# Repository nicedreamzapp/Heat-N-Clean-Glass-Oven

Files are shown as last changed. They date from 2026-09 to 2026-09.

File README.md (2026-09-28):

# Nice Dreamz Heat & Clean Glass Oven

**The perfect heat, every time. Drop in your terp slurper, banger, or ball vape -- the oven heats the entire barrel evenly to your exact target temperature. When you're done, crank it up and burn off all the char and resin too.**

**In one sentence:** an open-hardware design for a bolt-together stainless and ceramic oven that heats glass dab pieces to a set temperature with a PID controller, then runs hotter to burn them clean.

**Status:** design complete, 14-part metal fab package generated from Python CAD scripts, sheet thickness verified by measuring the STEP files. First physical articles are not in this repo yet (see [Known limits](#known-limits)).

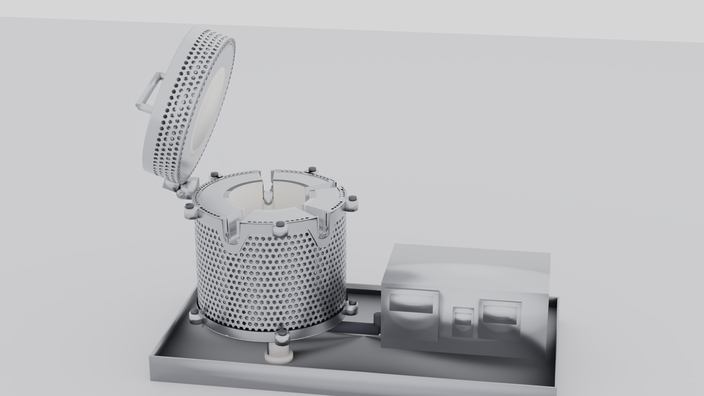
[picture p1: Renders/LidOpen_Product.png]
Nice Dreamz Heat & Clean Glass Oven - Lid Open


Heat & Clean is a precision ceramic oven that heats your glass pieces to the perfect dabbing or vaping temperature -- no torch, no guessing, no hot spots. Set your temp, drop in your piece, and get a perfect session every time. And when your glass gets gunked up? Same oven, higher temp, walk away. Comes back looking brand new.

**Spin every part in your browser — no CAD software needed:** https://nicedreamzapp.github.io/Heat-N-Clean-Glass-Oven/viewer-thickness.html
Click **Explode** to pull the oven apart, and every part is labelled with its sheet thickness.

**See every part in 3D (older viewer):** https://nicedreamzwholesale.com/heat-n-clean-viewer/all-parts.html
**Full parts list:** [PARTS_LIST.md](PARTS_LIST.md) · **Current fab package:** `CAD Exports/FAB_PACKAGE_2026-09-09/` — 14 STEP files + BOM

---

## What I built (Matt Macosko)

- **Parametric CAD generator**, all geometry in code: [Scripts/export_all_parts.py](Scripts/export_all_parts.py) (every part as STL/GLB), shared dimensions in [Scripts/hnc_params.py](Scripts/hnc_params.py), part builders [build_base_body.py](Scripts/build_base_body.py), [build_lid.py](Scripts/build_lid.py), [build_cap_shell_ring.py](Scripts/build_cap_shell_ring.py), [build_caps_tray.py](Scripts/build_caps_tray.py)
- **Fab package builder** for the 0.8 mm inner parts: [Scripts/build_inner_parts_08.py](Scripts/build_inner_parts_08.py) -> [CAD Exports/FAB_PACKAGE_2026-09-09/](CAD%20Exports/FAB_PACKAGE_2026-09-09/) (14 STEP files + [BOM](CAD%20Exports/FAB_PACKAGE_2026-09-09/BOM_metal_parts.csv))
- **Thickness verification** by ray-casting the STEP meshes: [Scripts/measure_thickness.py](Scripts/measure_thickness.py) -> [viewer-thickness/parts.json](viewer-thickness/parts.json), plus [Scripts/verify_steps.py](Scripts/verify_steps.py)
- **Flat patterns and shop drawings**: [generate_flat_patterns.py](Scripts/generate_flat_patterns.py), [generate_cap_dxfs.py](Scripts/generate_cap_dxfs.py), [generate_fab_package.py](Scripts/generate_fab_package.py) (bilingual EN/中文 spec)
- **Browser 3D viewers**: [viewer-thickness.html](viewer-thickness.html) and the other `viewer-*.html` pages
- **Controller configuration** for the upstream REX-C100 PID and DH48S timer: [Controller_Setup_Guide.md](Controller_Setup_Guide.md)
- **Parts list and assembly design** (25 pieces, zero welded joints): [PARTS_LIST.md](PARTS_LIST.md)

Upstream tools used, not written here: [build123d](https://github.com/gumyr/build123d) (STEP I/O), [trimesh](https://github.com/mikedh/trimesh), NumPy, [three.js](https://threejs.org/) (viewers), Blender (product renders). The REX-C100, DH48S and ceramic heater are off-the-shelf parts.

---

## Current metal spec (2026-09-09)

| | Parts | Sheet | Material |
|---|---|---|---|
| **Outside** — seen, structural | 02 outer tube · 04 bottom cap · 05 top cap · 07 lid outer tube · 08 lid top disk · 11 hinge strap | **1.2 mm** | 304SS, #4 brushed |
| **Inside** — hidden, no load | 01 inner wall · 03 support ring · 06 lid inner tube · 09 lid ceramic holder · 12 hold-down ring | **0.8 mm** | 304 **or** 430 SS / aluminized steel — anything rated 870 °F continuous |
| Tray | 14 steel tray | 3 mm | 304 or mild steel |
| Rod | 10 handle (Ø8) · 13 hinge pin (Ø5) | — | 304SS rod |

Inner wall ID stays 141.7 and the outer tube stays 152.1 / 154.5, so nothing that mates
with the ceramic or the glass moved. Every thickness above was measured back out of the
STEP files themselves (`Scripts/measure_thickness.py`), not copied from a spec sheet.

---

## The Problem

Torches and coil heaters can't evenly heat modern glass pieces.

| | |
|---|---|
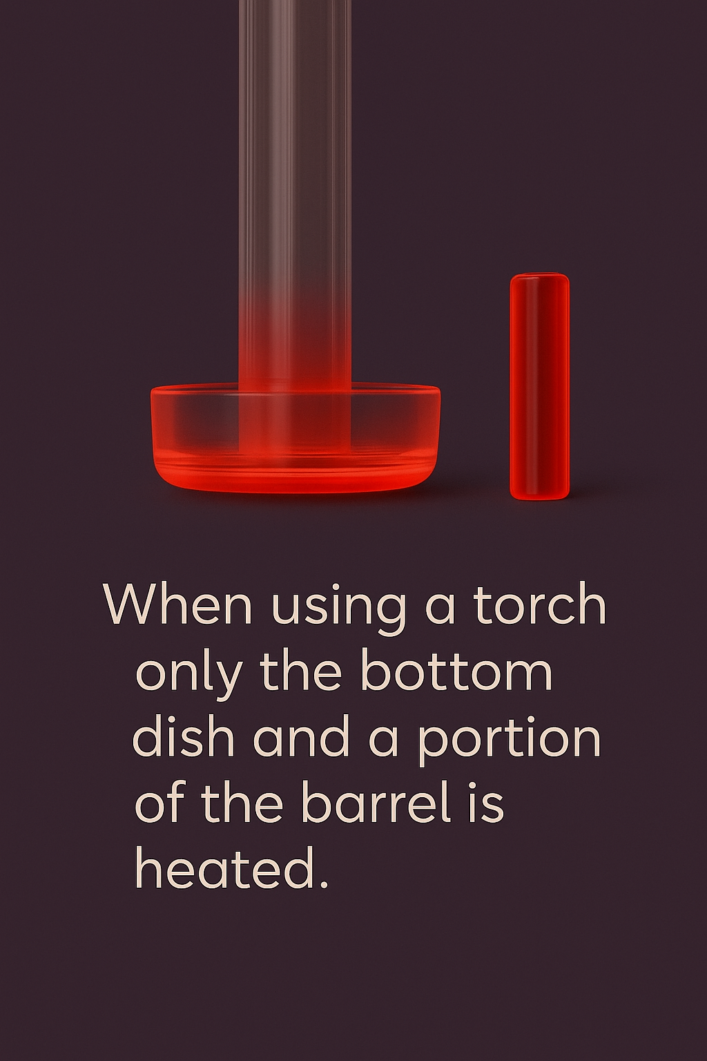
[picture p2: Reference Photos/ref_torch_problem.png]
Torch only heats the bottom
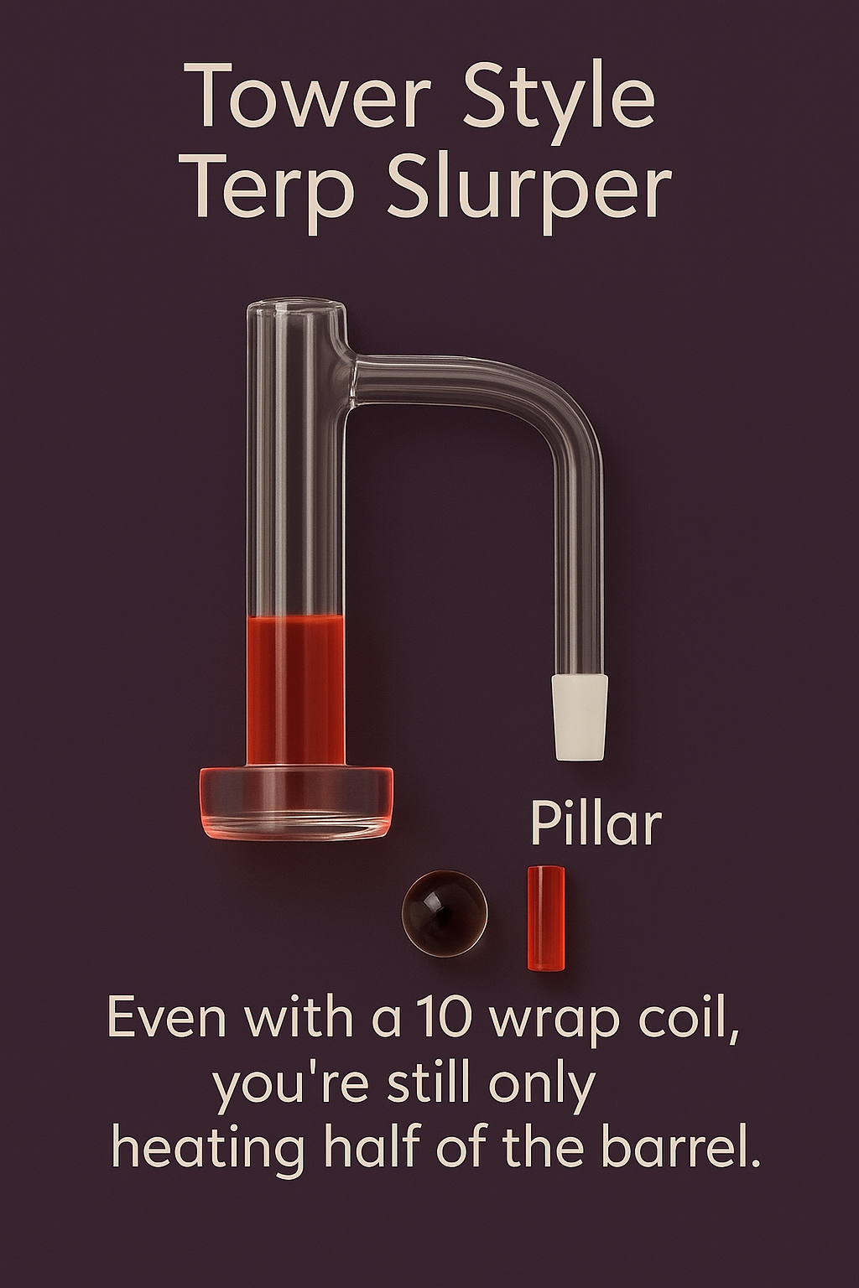
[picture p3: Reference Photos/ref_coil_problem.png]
Coil wraps only cover half the barrel
|  |  |

**With a torch**, only the bottom dish and a small portion of the barrel gets heated. You're guessing at temperature every single time -- too hot and you scorch it, too cool and you waste product.

**With a coil heater**, even a 10-wrap coil only covers half the barrel. The top half never reaches temp. Uneven heat means uneven flavor.

---

## The Solution

The Heat & Clean oven surrounds the **entire piece** in even, controlled heat.

| | |
|---|---|
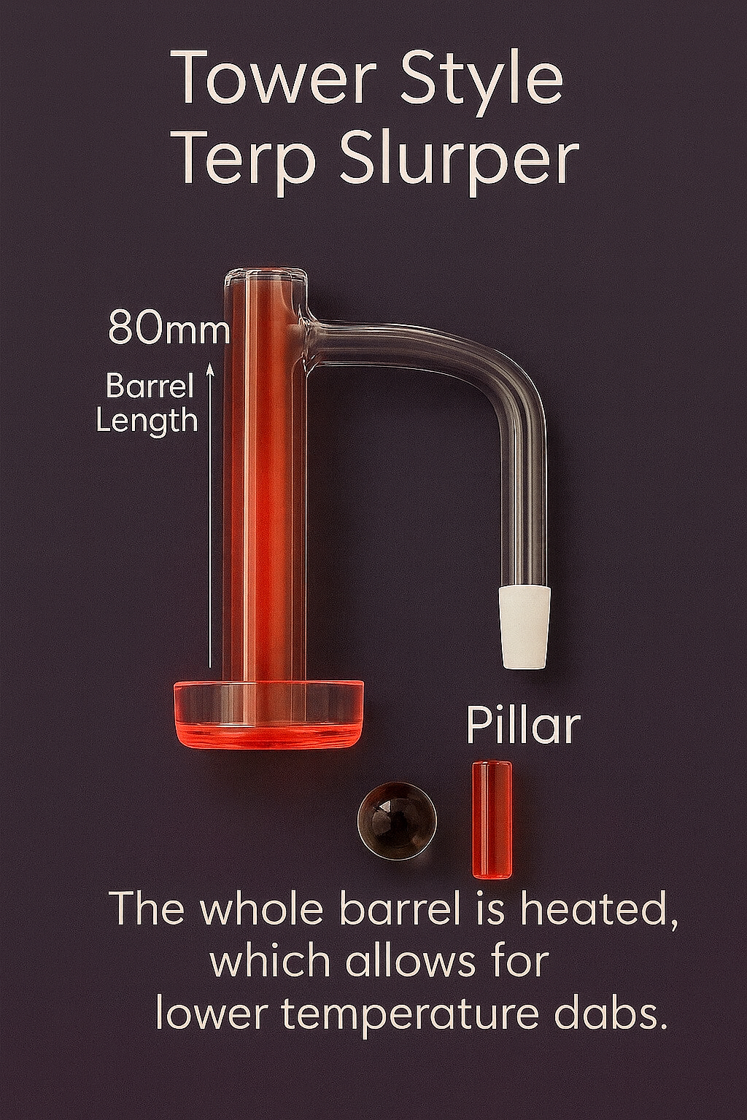
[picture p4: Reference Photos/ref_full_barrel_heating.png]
Full barrel heating
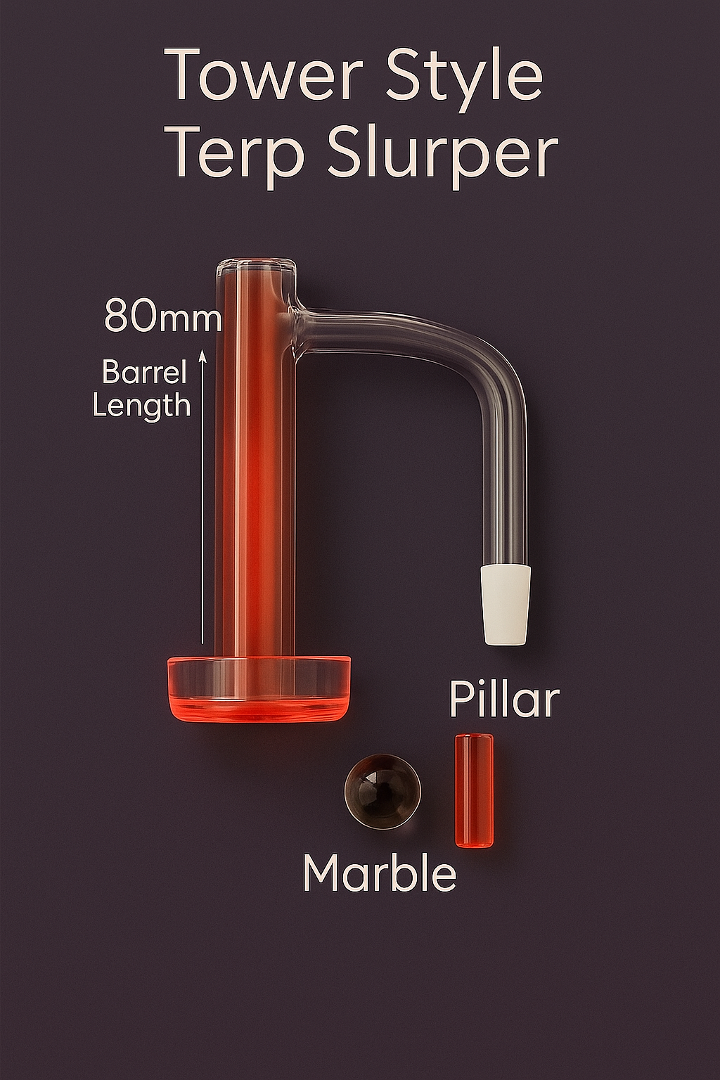
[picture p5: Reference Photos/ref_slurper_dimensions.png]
Terp slurper dimensions
|  |  |

The 91mm tall ceramic chamber heats the **whole barrel** -- top to bottom, all the way around. Tower-style terp slurpers with 80mm barrels fit completely inside. Set your exact target temperature and hit it every time. Lower temps, better flavor, zero waste.

---

## Two Modes, One Device

### Heating Mode
Drop in your terp slurper, banger, or ball vape heater. Set your preferred dabbing or vaping temperature -- most sessions run in the 500-600 F sweet spot. The PID controller brings it to temp and holds it perfectly. Pull it out, attach it, and enjoy a perfect session every time.

### Cleaning Mode
Crank the temperature up. Walk away. The oven burns off all char, resin, and buildup. Come back to glass that looks brand new. No chemicals, no scrubbing, no soaking. The 6-hour auto-shutoff timer means you can set it and forget it.

---

## Built To Be Built — zero welds, all bolts

The entire oven assembles with **M6 bolts and nuts**. The only welds in the
product are the seams of the rolled tubes. No welded brackets, no welded
bosses, no welded hinge. 25 numbered pieces per kit, 3 fastener types total.

- **Two-piece top cap** -- a laser-cut-and-formed shell (flat top, skirt, 6
  drop fingers that bolt to the existing spacer-ring bolts) plus a clamp-fit
  hold-down ring that grips the ceramic with **zero fasteners of its own** --
  it gets sandwiched when the cap bolts down.
- **Bolted strap hinge** -- the cap shell carries two curled knuckles on its
  hinge finger; a small strap bolts under one of the lid's existing bolts and
  carries the third knuckle; a 5mm pin ties them together. Low-profile: the
  knuckles sit just above the rim, slid sideways along the hinge line so they
  clear the bolt head.
- **Flush ceramic lid face** -- the ceramic disk sits dead flush with the
  lid's bottom plane. No recess, no proud lip.
- **Handle with threaded studs** -- no screw heads on the lid top; two nuts
  grab the studs from underneath.

## The design journey (June 2026)

This repo went through a full manufacturability redesign, live, with every
decision reviewed against 3D renders before any shop quotes:

1. The original one-piece top cap had four concentric walls hanging under it
   -- unmakeable from sheet, ~$500+ machined from billet. It became two cheap
   parts (shell + clamp ring).
2. Welded mounting bosses became drop fingers that reuse the spacer-ring
   bolts. The welded plate hinge became the bolted strap hinge.
3. Design review by eye caught and fixed, in order: a missing bolt hole in
   the strap, a strap too small for M6 hardware, a bolt-head/knuckle
   collision (fixed by sliding the knuckles sideways), painted-on holes that
   weren't really cut (now real boolean-cut holes), and a recessed ceramic
   lid face (now flush). The commit log tells the whole story.
4. Open question for first articles: hinge strap stiffness with the lid
   hanging open. Cheap fixes ready if needed: 1.5mm strap stock or a second
   bolt hole.

---

## Features

- **Precision PID temperature control** -- REX-C100 controller holds your target temp within a few degrees
- **Locked-down interface** -- just set your temp and go, no confusing menus
- **Triple safety system** -- software limit (870 F) + overheat alarm (900 F) + thermal fuse (930 F)
- **6-hour auto-shutoff** -- DH48S timer relay cuts power automatically
- **Insulated dual-wall construction** -- 31mm ceramic-to-outer-wall gap keeps exterior cool to the touch
- **Perforated mesh exterior** -- full airflow ventilation with clean stainless steel look
- **Ceramic feet** -- heat-insulating legs keep the steel tray cool
- **Bolted strap hinge** -- lid swings open past vertical for easy loading; flush ceramic disk seals the chamber
- **Clamp-fit hold-down ring** -- keeps the ceramic core centered and seated with no fasteners of its own

---

## What's Inside

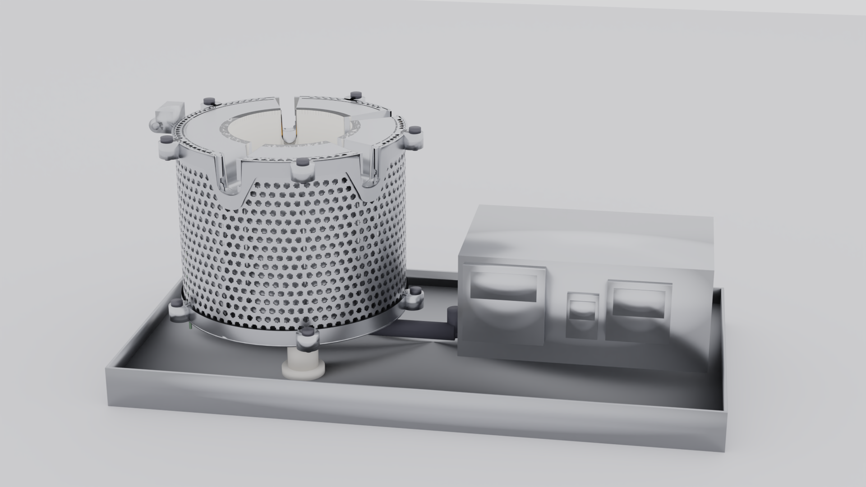
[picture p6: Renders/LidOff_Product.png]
Nice Dreamz Heat & Clean Glass Oven - Lid Removed


| Component | Material |
|---|---|
| Heating chamber | High-alumina ceramic cylinder (92.5mm OD) |
| Heating element | Kanthal wire coil (30 wraps) |
| Inner housing | 0.8mm 304 or 430 SS / aluminized steel (see metal spec above) |
| Outer mesh | 1.2mm perforated 304 stainless steel |
| Insulation gap | 24.6mm air gap between ceramic and housing |
| Spacer rings | 5x ceramic (3x 14mm body + 2x 10mm lid) |
| Controller | REX-C100 PID + SSR + DH48S timer |
| Legs | 3x ceramic feet with M6 mounting |

---

## Specifications

| Spec | Value |
|---|---|
| Chamber ID | 81.5 mm (3.2 in) |
| Chamber height | 91 mm (3.6 in) |
| Outer diameter | 154.5 mm (6.1 in) |
| Temperature range | 100 - 870 F |
| Power | 120V AC |
| Auto-shutoff | 6 hours |
| Wall thickness | 31 mm (ceramic to outer mesh) |
| Body material | 304 stainless steel, brushed finish |

---

## Works With

- Tower-style terp slurpers (up to 80mm barrel)
- Standard bangers
- Ball vape heaters
- Any glass piece that fits the 81.5mm chamber

---

## Known limits

- No physical prototype results are in this repo. Temperatures and safety limits are the controller settings in [Controller_Setup_Guide.md](Controller_Setup_Guide.md), not logged test data.
- Hinge strap stiffness with the lid open is still an open question (see the design journey above).
- `build_inner_parts_08.py` and `measure_thickness.py` read some files from `Factory Files/`, which is gitignored, so the 2026-09-09 fab package cannot be fully rebuilt from this repo alone. The committed STEP files are the source of truth.
- `export_all_parts.py` still models every sheet at 1.2 mm; the 0.8 mm inner parts exist only in the fab package STEP files.
- There is no `requirements.txt`. The scripts expect a local venv (`.venv-cad`) with build123d, trimesh and numpy.

---

## Quick start

```bash
# View the parts in a browser (the viewers load files by relative path)
python3 -m http.server        # then open http://localhost:8000/viewer-thickness.html

# Regenerate the STL/GLB meshes
python3 -m venv .venv-cad && .venv-cad/bin/pip install build123d trimesh numpy
.venv-cad/bin/python Scripts/export_all_parts.py
```

---

## License

Open hardware, copyleft: CERN-OHL-S-2.0 for the hardware and CAD, GPL-3.0-or-later for code, CC-BY-SA-4.0 for docs and images. See [LICENSE](LICENSE) for which applies to what.

---

## Project Structure

```
PARTS_LIST.md                   -- the 25-piece kit, numbered like the viewer labels
Scripts/
  export_all_parts.py           -- generates every part as STL/GLB (all sheets at 1.2 mm)
  hnc_params.py                 -- shared dimensions (outer 1.2 mm, inner 0.8 mm)
  build_inner_parts_08.py       -- builds the 14-part STEP package in FAB_PACKAGE_2026-09-09/
  measure_thickness.py          -- measures sheet thickness from the STEPs, feeds viewer-thickness
  generate_fab_package.py       -- builds the bilingual shop quote package + zip
  generate_cap_dxfs.py          -- cap shell flat blank + hold-down ring drawing (DXF)
  generate_flat_patterns.py     -- laser-cut flat patterns for the other parts

viewer-*.html                   -- interactive 3D viewers (serve repo root, e.g. python3 -m http.server)
  viewer-thickness.html         -- current 14 metal parts, measured thickness, explode (hosted on GitHub Pages)
  viewer-sections.html          -- all 25 pieces, separated + named (hosted: /heat-n-clean-viewer/all-parts.html)
  viewer-metal-parts.html       -- the 13 metal parts a shop quotes
  viewer-topcap-fastening.html  -- full assembly; fasten/open-lid animations
  viewer-hinge-closeup.html     -- strap hinge close-up, attach animation
  viewer-full-assembly.html     -- every piece, apart/together
  viewer-capshell.html          -- the cap shell alone

CAD Exports/
  FAB_PACKAGE_2026-09-09/       -- current: 14 STEP files + BOM + README
  Individual Parts/STL|GLB/     -- every part as STL/GLB
  Core Split/ · Lid Split/      -- the split parts the viewers load
  Flat Patterns/DXF|SVG/        -- laser-cut patterns
  Fabrication Package/          -- older package: spec EN + 中文, BOM, DXF, 3D refs (zip alongside)
```

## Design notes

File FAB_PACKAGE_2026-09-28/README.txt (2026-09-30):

Heat & Clean Glass Oven: machining files, 2026-09-28
Replaces every earlier package. Metal parts only; we supply all ceramics.

Look at the 3D first:
  Base:  https://nicedreamzapp.github.io/Heat-N-Clean-Glass-Oven/viewer-base-full.html
  Lid:   https://nicedreamzapp.github.io/Heat-N-Clean-Glass-Oven/viewer-lid-full.html
  Whole oven, lid open: https://nicedreamzapp.github.io/Heat-N-Clean-Glass-Oven/viewer-complete.html

Changes from the files you have:
  05 Top Cap: ONE piece (not shell + ring). Flat top sits on the tube tops, open in the middle over the ceramic core.
  05 Top Cap: each of the 4 glass slots has a metal groove the exact shape of the ceramic slot (10.5 mm wide, round R5.25 bottom, 23.5 mm deep) welded under the cap, flush with the ceramic slot and butted right against the ceramic. ONE groove per slot, from the ceramic straight out to the outer tube. The inner tube's 4 glass slots are widened (13.3 mm, round bottom) so the groove passes through, so the insulation is never open and the cap stays one piece.
     Sleeves hug the ceramic, the inner tube and the outer tube. 6 tabs come down the outside and bolt through the
     top bolts. 4 glass slots straight through, lined up with the walls. Vent holes over the gap between the tubes.
  03 Support Ring: new short wall around the edge with 6 bolt holes (the seat bolts hold it).
     3 new holes in the flat plate for the heater wires (Ø8 x2) and thermocouple (Ø6.4).
  04 Bottom Cap: 3 holes right under those (same positions). Old wire holes near the edge are closed.
  01 Inner Wall Tube: no wire slot and no thermocouple hole anymore. Solid except the glass slots and bolt holes.
  08 Lid Top Disk: 6 holes in the skirt for the upper lid bolts.
  09 Lid Ceramic Holder: pocket that wraps the ceramic lid disk edge and holds it from above; 6 bolt holes in its upright wall.
  Lid parts sit 1.2 mm higher than before, on top of the top cap.
  Hinge: use your stock stainless butt hinge (approved Sept 11). Please add its screw holes to the top cap and lid; the strap + pin in these files is only a placeholder.
  Inside parts (01, 03, 06, 09) are 0.8 mm. Outside parts are 1.2 mm. Tray 3 mm.

Fit fixes, 2026-09-30 (same files, updated):
  03 / 04 / 14: the 3 leg screw holes moved in to r 64.0 (were r 65.85) so the screw heads clear the inner tube. 04's leg holes are now Ø6.6 (were Ø13.2).
  03 / 04: the 2 heater wire holes are at 180° and 190° (were 183° and 188°, which ran together into one slot).
  03: 0.2 mm clearance to the inner tube and to the ceramic base disk.
  01: all 4 glass slots are the same 13.3 mm now (one still had a step from the old wire slot).
  04: the old wire holes are fully closed, including the side wall.
  09: the upright wall and the small outer lip sit 0.2 mm inside the lid tubes (they overlapped the tube walls).
  06 / 07: 0.8 mm shorter at the bottom; they stand on 09's plate.
  08 / 10: the handle screws on. 2 x Ø4.5 holes in the lid top disk, M4 tapped hole 10 mm deep in each handle post, M4 screws from inside the lid.

加热清洁玻璃炉：加工文件，2026-09-28
替换之前所有的文件包。只包括金属件，陶瓷件全部由我方提供。

请先看3D：
  底座：https://nicedreamzapp.github.io/Heat-N-Clean-Glass-Oven/viewer-base-full.html
  盖子：https://nicedreamzapp.github.io/Heat-N-Clean-Glass-Oven/viewer-lid-full.html
  整机（盖子打开）：https://nicedreamzapp.github.io/Heat-N-Clean-Glass-Oven/viewer-complete.html

和你手上的文件相比的改动：
  05 顶盖：改成一整件（不是外壳加压环）。平顶放在两根管子上面，中间对着陶瓷芯是开口的。
  05 顶盖：4个玻璃槽下面各焊一个金属槽，形状与陶瓷槽完全一样（宽10.5毫米，R5.25圆底，深23.5毫米），紧贴陶瓷。每个槽是一整条，从陶瓷一直到外管。内管的4个玻璃槽加宽到13.3毫米（圆底），让金属槽穿过，保温棉不外露，顶盖仍是一整件。
     套边分别贴住陶瓷、内管和外管。6个折边片沿外侧往下，用最上面一排螺栓固定。4个玻璃槽直通，和管壁的槽对齐。两根管子之间的位置有通风孔。
  03 支撑环：边缘加一圈矮墙，上面有6个螺栓孔（用座圈螺栓固定）。平板上加3个孔：加热丝 Ø8 两个，热电偶 Ø6.4 一个。
  04 底盖：在这3个孔正下方加3个孔（位置相同）。靠边缘的旧线孔封掉。
  01 内壁管：不再有线槽和热电偶孔。除了玻璃槽和螺栓孔，其他地方都是实心的。
  08 盖子顶盘：裙边上加6个孔，用于盖子上排螺栓。
  09 盖子陶瓷托架：包住陶瓷盖盘边缘、从上方固定的槽位；立墙上有6个螺栓孔。
  盖子所有零件比以前高1.2mm，放在顶盖上面。
  铰链：用你们的现成不锈钢合页（9月11日已确认）。请在顶盖和盖子上加它的螺丝孔；文件里的铰链片和销只是示意。
  内部件（01、03、06、09）厚度0.8mm，外部件1.2mm，托盘3mm。

装配修正，2026-09-30（同一批文件，已更新）：
  03 / 04 / 14：3个脚螺丝孔往里移到 r 64.0（原来 r 65.85），螺丝头不再碰内管。04 的脚孔改为 Ø6.6（原来 Ø13.2）。
  03 / 04：2个加热线孔在 180° 和 190°（原来 183° 和 188°，两孔连成一条槽）。
  03：和内管、陶瓷底盘之间留 0.2mm 间隙。
  01：4个玻璃槽现在都是 13.3mm（其中一个还留着旧线槽的台阶）。
  04：旧线孔完全封住，包括侧壁。
  09：立墙和外侧小边都在盖子管子里面 0.2mm（原来和管壁重叠）。
  06 / 07：底部短 0.8mm，立在 09 的底板上。
  08 / 10：提手用螺丝固定。盖子顶盘上开 2 个 Ø4.5 孔，提手每个脚上攻 M4 螺纹孔（深 10mm），M4 螺丝从盖子里面往上拧。

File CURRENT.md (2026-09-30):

# CURRENT: the only files to build from (2026-09-28)

Everything older was moved OFF GitHub to the local folder `Desktop/PROJECTS/Heat-N-Clean-ARCHIVE (old, do not build from)`. Never render, measure or build from it.

| Page | What it is |
|---|---|
| viewer-base-full.html | Base, every part, cut in half, measurements |
| viewer-base-assembly.html | Base, step-by-step build |
| viewer-lid-full.html | Lid, every part, cut in half |
| viewer-lid-assembly.html | Lid, step-by-step build |
| viewer-lid-holder.html | Lid ceramic holder + ceramic lid disk on the core |
| viewer-complete.html | Whole oven, lid open on its hinge, cut in half / separated (one of the 3 links for Tianrun) |

| Oven_All_Parts_2026-09-30.png | Letter-size sheet, every part laid out, EN + 中文 (made by viewer-parts-sheet.html) |

Meshes: `viewer-full/` (base) and `viewer-lid-full/` (lid). Those are the approved shapes. `viewer-full/tray.glb` is the steel tray, unchanged since June, copied in from the archive on 2026-09-28.
Machining files: `FAB_PACKAGE_2026-09-28/` (STEP + STL + bilingual README), built by `Scripts/build_current_package.py` from `cad-source/` (Sept 9 solids for unchanged parts) plus every 2026-09-28 change in code.
05 top cap is a clean solid (2026-09-28 redraw, sleeves 0.2 mm clear). The lid sits on it, so every lid part is +1.2 mm except the ceramic lid disk.
Hinge: LEFT TO TIANRUN'S SHOP (Matt, 2026-09-28); the README tells them. Was: Alice's stock butt hinge was approved 2026-09-11, but the model still shows the old strap + pin, and the cap has no hinge mount.

2026-09-28 evening: 05 top cap has 4 metal slot grooves (inside = the ceramic slot exactly: 10.5 wide, R5.25 round bottom, 23.5 deep), one per slot from the ceramic to the outer tube; they cover the insulation and keep the cap one piece. 01 inner tube glass slots widened to 13.3 (round bottom) so the grooves pass. 01 STEP is now a single solid (the wire-hole patches used to come out as loose pieces).

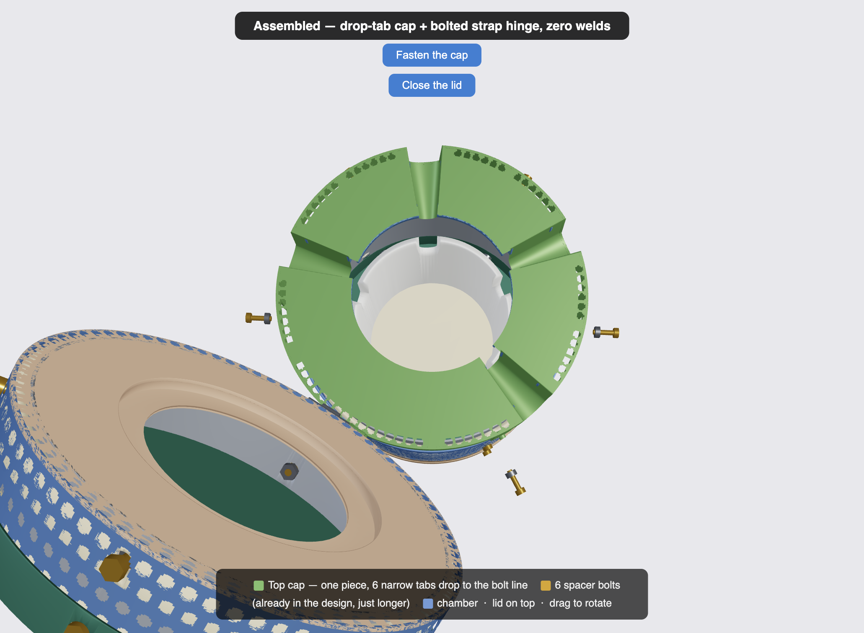
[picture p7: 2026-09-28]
.qc_lid_inside.png

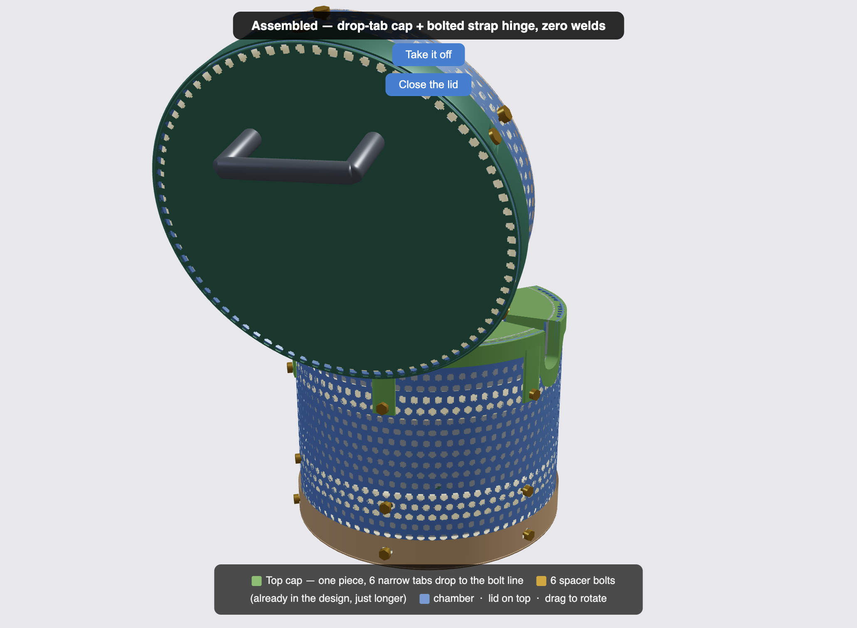
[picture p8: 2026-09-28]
.qc_final_open.png

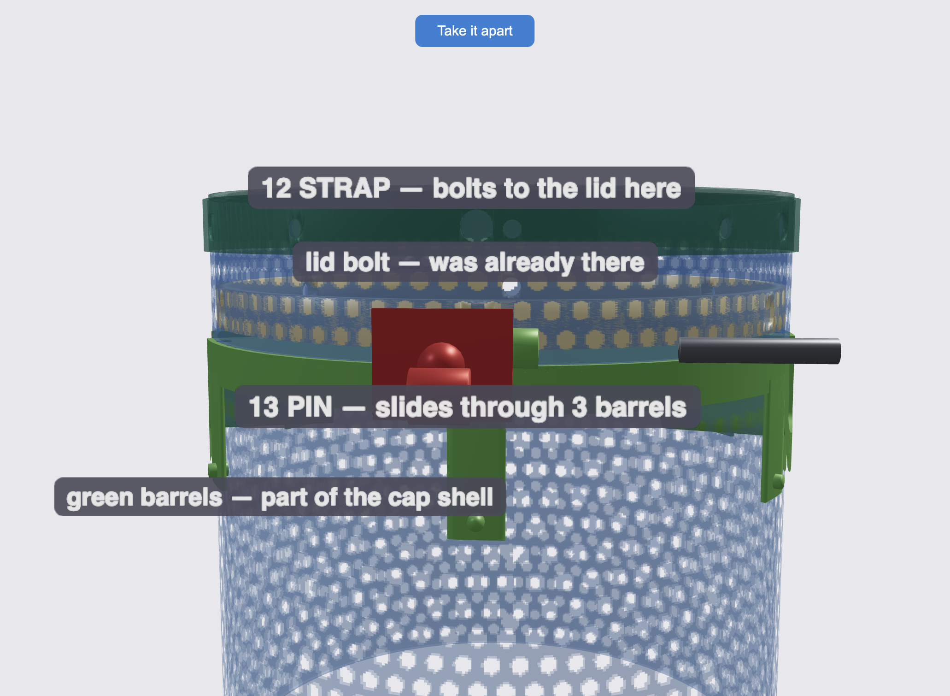
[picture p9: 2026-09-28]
.qc_his_screen.png

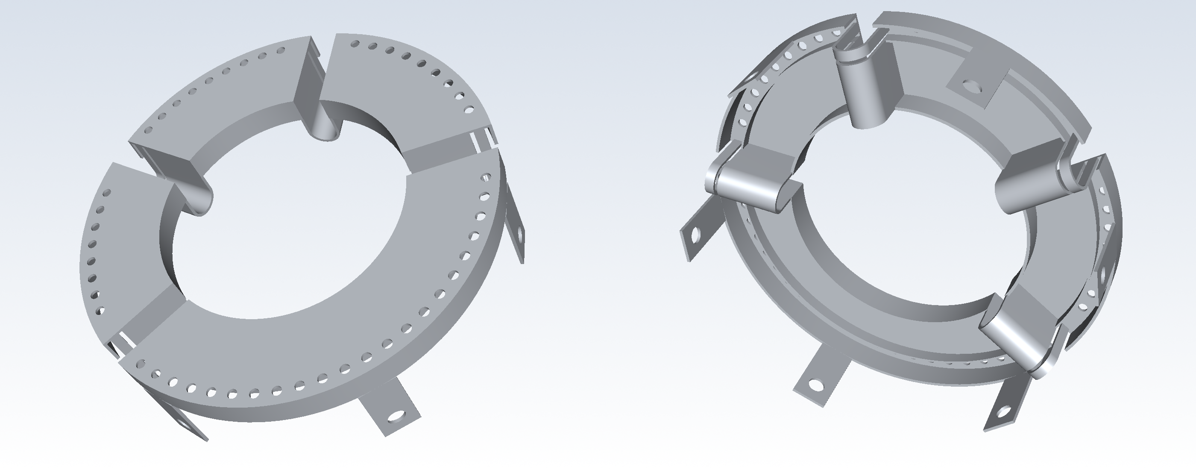
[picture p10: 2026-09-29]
Renders/top_cap_alone_2026-09-28.png

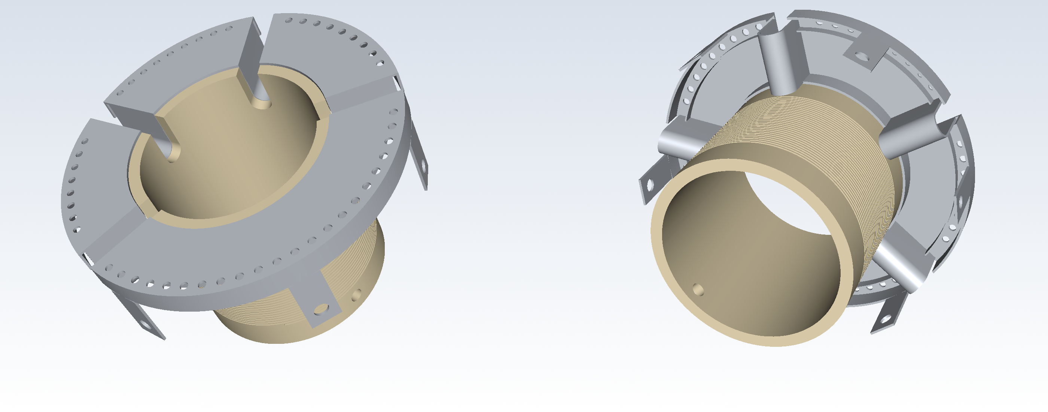
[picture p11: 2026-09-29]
Renders/top_cap_with_core_2026-09-28.png

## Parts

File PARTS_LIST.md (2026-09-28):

# Heat-N-Clean — Parts List (final design, 2026-06-10)

One kit = **25 numbered pieces**. Numbers match the labels in the
[interactive viewer](https://nicedreamzwholesale.com/heat-n-clean-viewer/all-parts.html)
(`viewer-sections.html` locally).

Zero welds anywhere. Every joint is a bolt, a nut, or a clamp fit.

## BODY (1–12)

| # | Part | Qty | Notes |
|---|---|-----|---|
| 1 | Bottom Cap | 1 | fastened by the bottom long-bolt ring |
| 2 | Ceramic Base Disk | 1 | |
| 3 | Support Ring | 1 | |
| 4 | Ceramic Heater Core | 1 | 4 glass slots |
| 5 | Seat Spacer Ring | 1 | ceramic, 14mm tall |
| 6 | Inner Wall Tube | 1 | |
| 7 | Top Spacer Ring | 1 | ceramic, 14mm tall |
| 8 | Outer Perforated Tube | 1 | |
| 9 | Bottom Spacer Ring | 1 | ceramic, 14mm tall |
| 10 | Seat Bolts + Nuts | 6 + 6 | M6 short |
| 11 | Cap-Finger Bolts + Nuts | 6 + 6 | M6 long — also clamp the Cap Shell fingers |
| 12 | Bottom Bolts + Nuts | 6 + 6 | M6 long — also clamp the Bottom Cap |

## TOP CAP (13–14) — two pieces, no fasteners between them

| # | Part | Qty | Notes |
|---|---|-----|---|
| 13 | Ceramic Hold-Down Ring | 1 | flat ring + 3 hanging walls; CLAMP FIT — trapped between shell and chamber, no screws |
| 14 | Cap Shell | 1 | one sheet: top, skirt, 6 drop fingers, hinge finger w/ 2 curl barrels |

## LID (15–25)

| # | Part | Qty | Notes |
|---|---|-----|---|
| 15 | Ceramic Lid Disk | 1 | |
| 16 | Lid Ceramic Holder | 1 | |
| 17 | Lower Lid Spacer Ring | 1 | ceramic, 10mm tall |
| 18 | Lid Inner Tube | 1 | |
| 19 | Upper Lid Spacer Ring | 1 | ceramic, 10mm tall |
| 20 | Lid Outer Perforated Tube | 1 | |
| 21 | Lid Top Disk | 1 | |
| 22 | Handle | 1 | threaded studs built into the feet — no screw heads on top |
| 23 | Handle Nuts | 2 | grab the studs under the Lid Top Disk |
| 24 | Lower Lid Bolts + Nuts | 6 + 6 | M6 short |
| 25 | Upper Lid Bolts + Nuts | 6 + 6 | M6 short |

## Hinge (bolted strap — zero welds)

- Cap side: built into the Cap Shell (#14) — the finger at 292.4° runs up past the rim into 2 curled barrels
- Lid side: `05b_Lid_Hinge_Strap` — bolts under the lid's existing bolt at 292.4°, 1 barrel
- `05_Hinge_Pin` slides through all 3 barrels

## Fastener + ceramic-ring totals per kit

| Item | Count |
|---|---|
| Ceramic spacer rings | **5** (3 body @ 14mm + 2 lid @ 10mm — same diameter, same bolt holes) |
| M6 short bolts | 18 |
| M6 long bolts | 12 |
| M6 nuts | 30 |
| Handle nuts | 2 |
| Hinge pin | 1 |

Only **3 fastener types** in the whole oven: short bolt, long bolt, nut.

> Open question: make all 5 spacer rings the same height → one ceramic ring part ×5.

## Regenerating everything

```bash
.venv/bin/python Scripts/export_all_parts.py
```

Exports every part (STL + GLB) to `CAD Exports/Individual Parts/`. The split
GLBs the viewers use live in `CAD Exports/Core Split/` and `CAD Exports/Lid Split/`.

Old fabrication package, STEP files, and the one-piece top cap were removed
2026-06-10 — they described the old design (welded bosses, 5-ear cap, plate
hinge, M4 cap screws) and need regenerating from the current model when a
shop package is next needed.

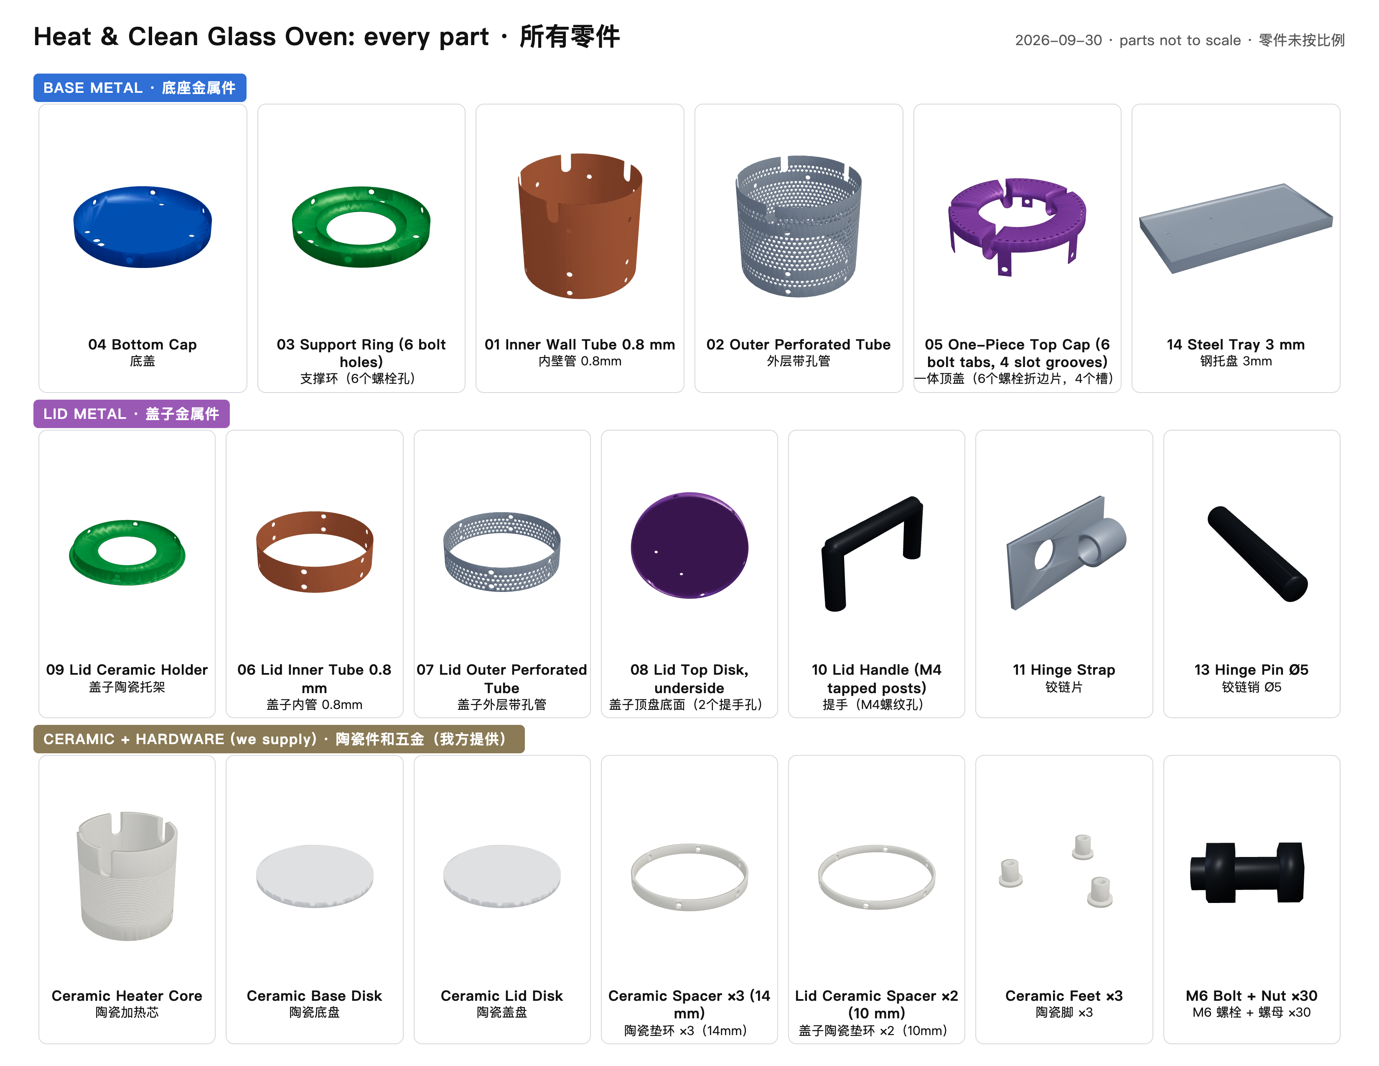
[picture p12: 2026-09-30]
Oven_All_Parts_2026-09-30.png

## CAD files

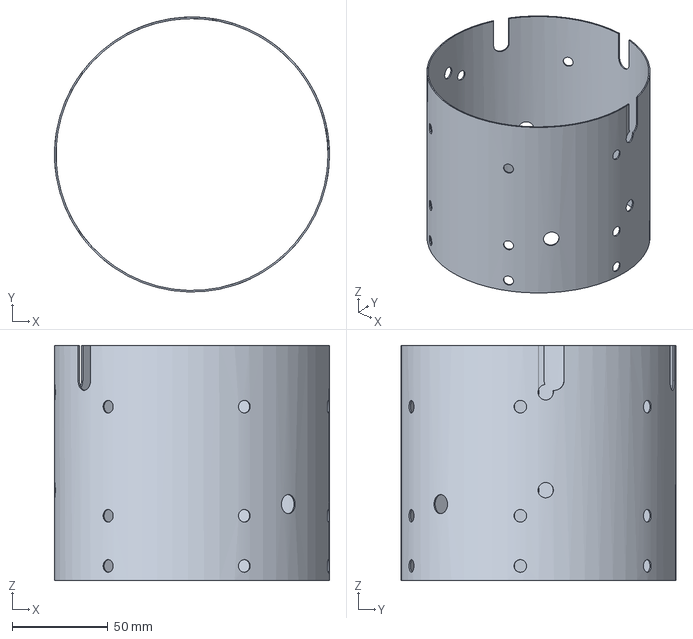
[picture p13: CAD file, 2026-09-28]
cad-source/01_Inner_Wall_Tube.step
143.3 x 143.2 x 122.7 mm

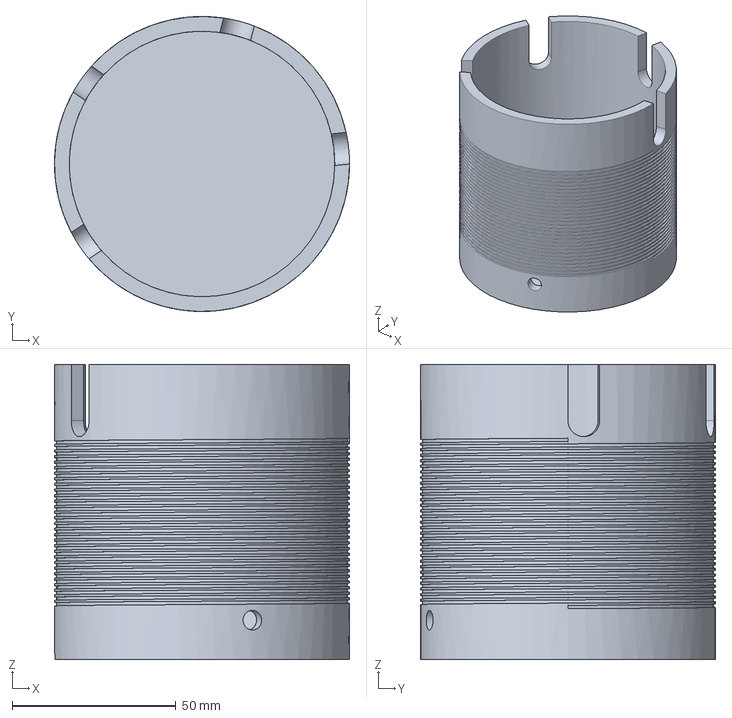
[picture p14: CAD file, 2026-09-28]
Ceramic Parts/ceramic heater_CAD.step
90.0 x 90.0 x 90.0 mm

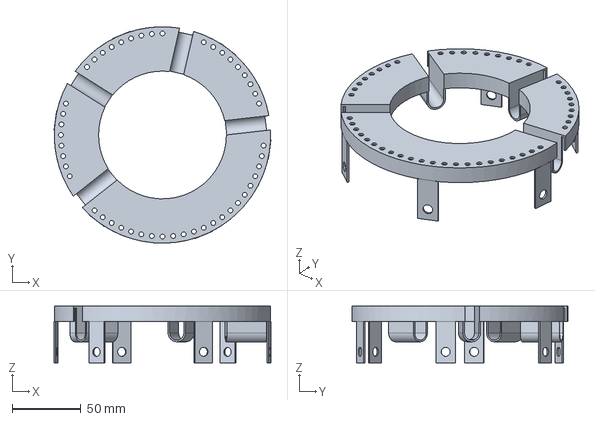
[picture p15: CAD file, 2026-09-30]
FAB_PACKAGE_2026-09-28/STEP/05_One_Piece_Top_Cap.step
157.8 x 157.3 x 41.2 mm

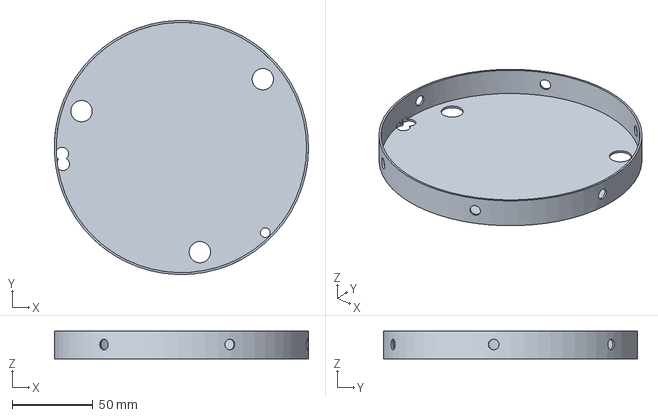
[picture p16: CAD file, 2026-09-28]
cad-source/04_Bottom_Cap.step
157.4 x 157.4 x 17.2 mm

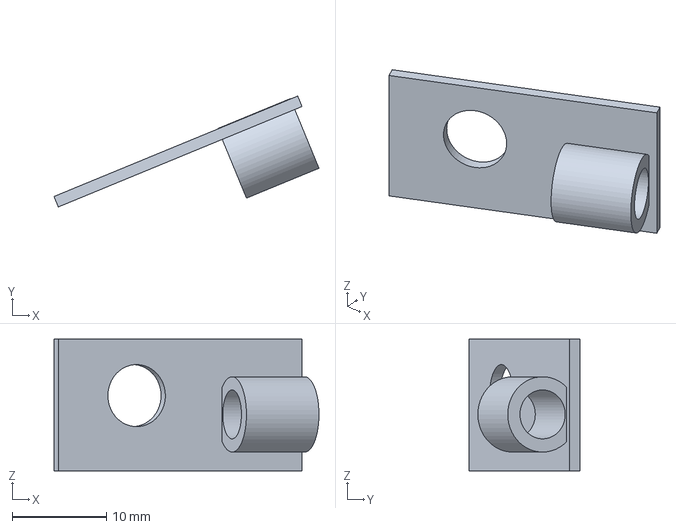
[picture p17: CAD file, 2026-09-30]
FAB_PACKAGE_2026-09-28/STEP/11_Lid_Hinge_Strap.step
28.1 x 11.8 x 14.0 mm

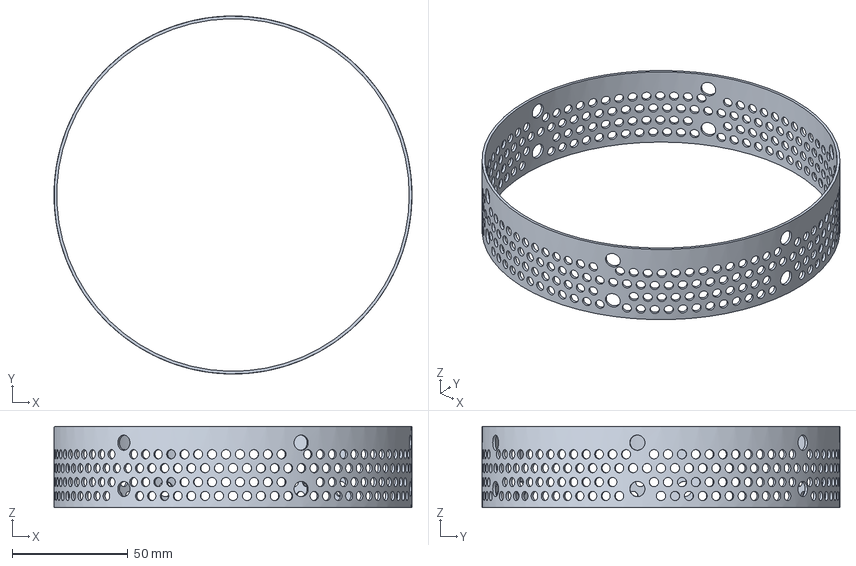
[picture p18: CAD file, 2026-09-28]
cad-source/07_Lid_Outer_Perforated_Tube.step
154.5 x 154.5 x 35.0 mm

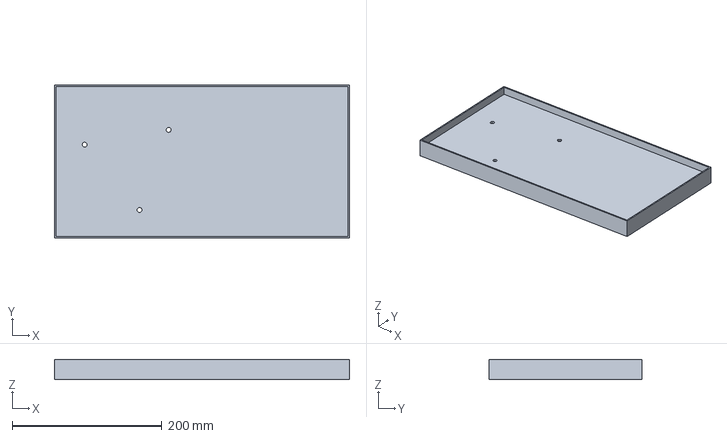
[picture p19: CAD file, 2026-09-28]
cad-source/14_Steel_Tray.step
394.5 x 204.5 x 27.0 mm

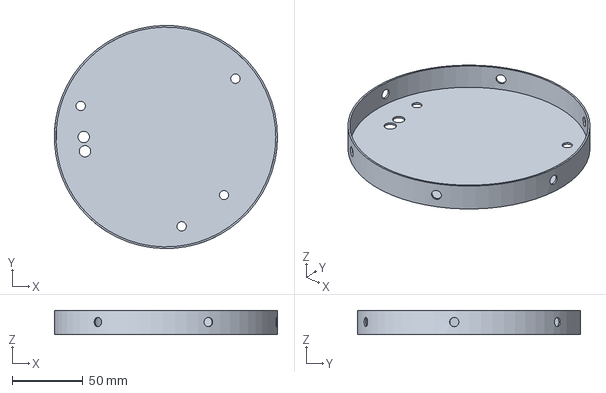
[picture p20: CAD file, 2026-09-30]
FAB_PACKAGE_2026-09-28/STEP/04_Bottom_Cap.step
157.4 x 157.4 x 17.2 mm

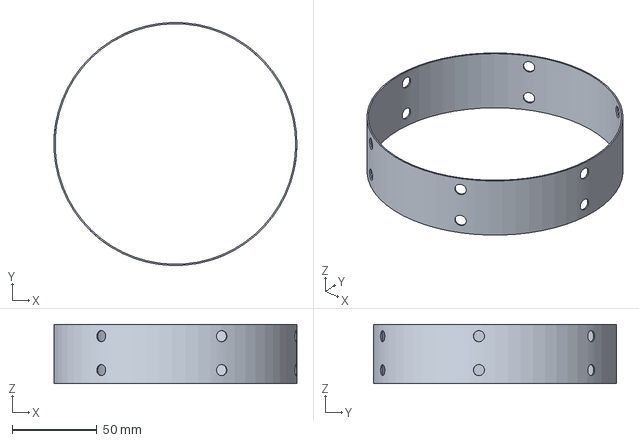
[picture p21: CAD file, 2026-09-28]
cad-source/06_Lid_Inner_Tube.step
143.2 x 143.2 x 35.0 mm

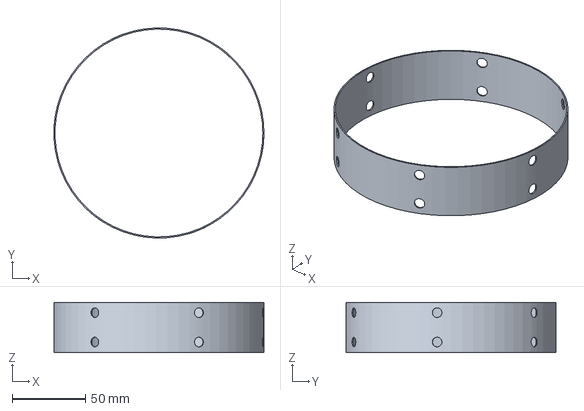
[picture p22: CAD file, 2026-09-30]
FAB_PACKAGE_2026-09-28/STEP/06_Lid_Inner_Tube.step
143.2 x 143.2 x 34.2 mm

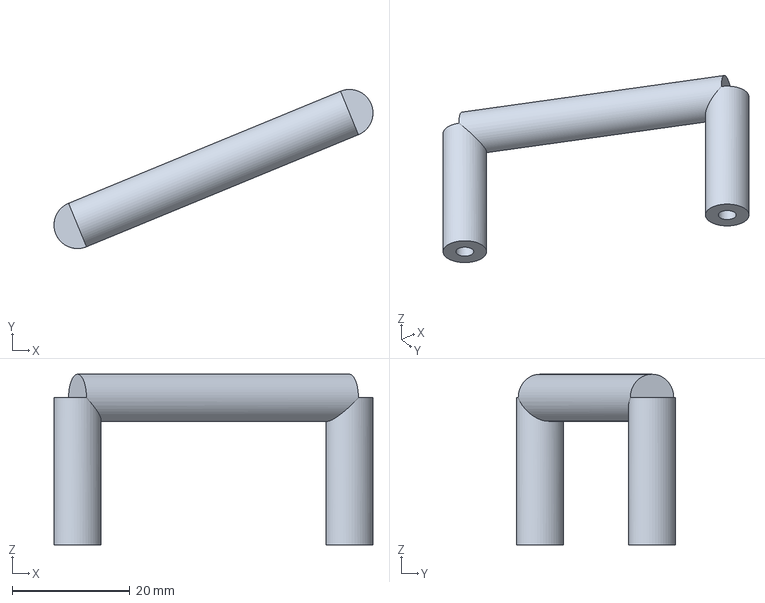
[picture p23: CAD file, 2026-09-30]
FAB_PACKAGE_2026-09-28/STEP/10_Lid_Handle.step
54.2 x 27.0 x 29.0 mm

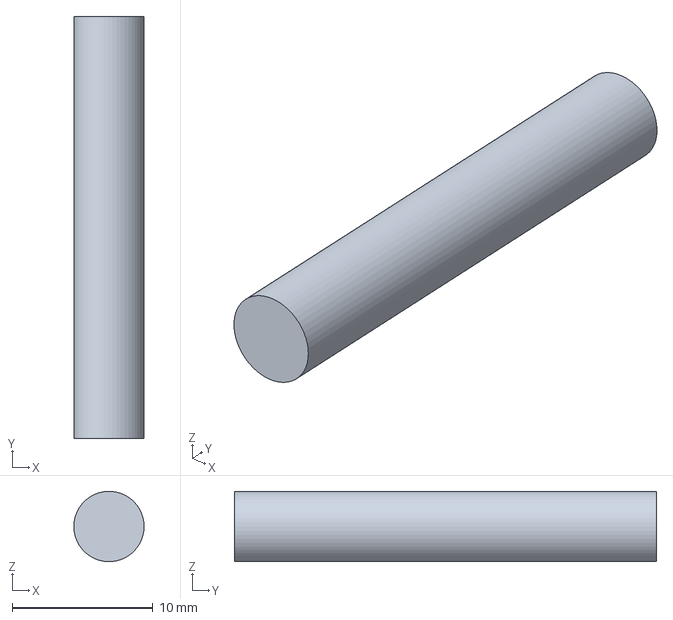
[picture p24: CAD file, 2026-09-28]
cad-source/13_Hinge_Pin.step
5.00 x 30.0 x 5.00 mm

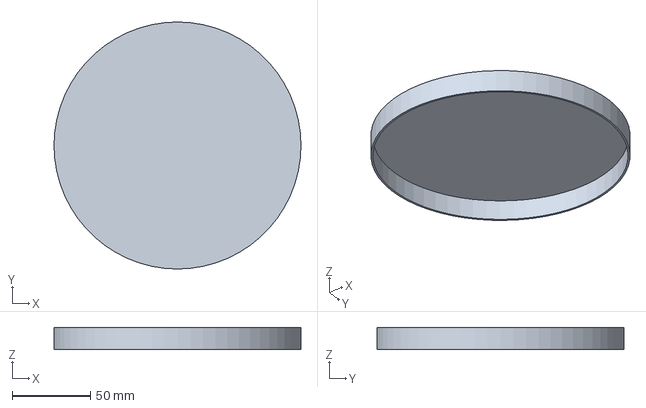
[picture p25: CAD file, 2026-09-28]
cad-source/08_Lid_Top_Disk.step
157.5 x 157.5 x 14.2 mm

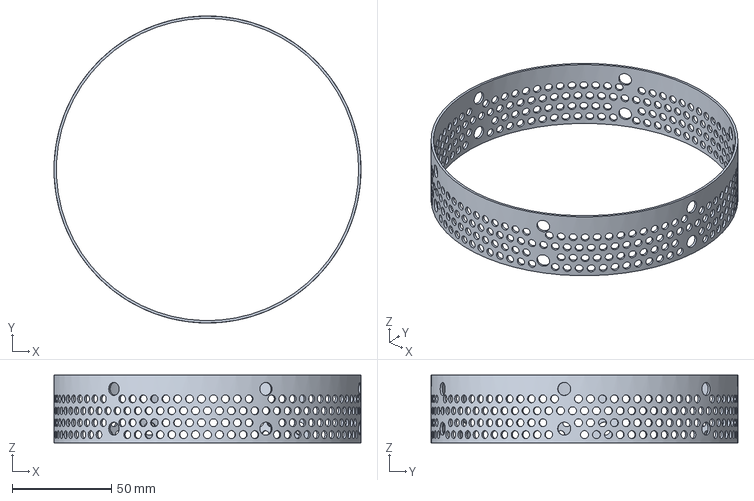
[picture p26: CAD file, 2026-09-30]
FAB_PACKAGE_2026-09-28/STEP/07_Lid_Outer_Perforated_Tube.step
154.5 x 154.5 x 34.2 mm

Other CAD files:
FAB_PACKAGE_2026-09-28/STL/02_Outer_Perforated_Tube.stl
FAB_PACKAGE_2026-09-28/STEP/01_Inner_Wall_Tube.step
cad-source/11_Lid_Hinge_Strap.step
FAB_PACKAGE_2026-09-28/STEP/13_Hinge_Pin.step
FAB_PACKAGE_2026-09-28/STEP/03_Support_Ring.step
FAB_PACKAGE_2026-09-28/STEP/08_Lid_Top_Disk.step
FAB_PACKAGE_2026-09-28/STEP/09_Lid_Ceramic_Holder.step
FAB_PACKAGE_2026-09-28/STEP/14_Steel_Tray.step
FAB_PACKAGE_2026-09-28/STL/01_Inner_Wall_Tube.stl
FAB_PACKAGE_2026-09-28/STL/03_Support_Ring.stl
FAB_PACKAGE_2026-09-28/STL/04_Bottom_Cap.stl
FAB_PACKAGE_2026-09-28/STL/05_One_Piece_Top_Cap.stl
FAB_PACKAGE_2026-09-28/STL/06_Lid_Inner_Tube.stl
FAB_PACKAGE_2026-09-28/STL/07_Lid_Outer_Perforated_Tube.stl
FAB_PACKAGE_2026-09-28/STL/08_Lid_Top_Disk.stl
FAB_PACKAGE_2026-09-28/STL/09_Lid_Ceramic_Holder.stl
FAB_PACKAGE_2026-09-28/STL/10_Lid_Handle.stl
FAB_PACKAGE_2026-09-28/STL/11_Lid_Hinge_Strap.stl
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

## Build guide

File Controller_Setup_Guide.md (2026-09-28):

# REX-C100 Controller Setup Guide — Heat-N-Clean Glass Oven

## Overview

Each unit ships with a REX-C100 PID controller locked to 100–870°F.
Customer can ONLY change the target temperature. All other settings are locked.

---

## Parts List (Controller Box)

| Part | Purpose | Cost |
|---|---|---|
| REX-C100 (K-type, SSR output) | Temperature control | ~$10 |
| DH48S-2Z timer relay | 6-hour auto-shutoff | ~$10 |
| SSR (40A solid state relay) | Switches Kanthal coil | ~$5 |
| On/Off switch | Master power | ~$2 |
| Inline fuse | Surge protection | ~$0.50 |
| Thermal fuse (~900°F) | Failsafe on oven body | ~$1 |

**Total controller cost: ~$28-30 per unit**

---

## Wiring Order

```
Wall Power (120V AC) → On/Off Switch → DH48S Timer → REX-C100 Power
                                                        ↓
                                              REX-C100 SSR Output → SSR → Kanthal Coil
                                                        ↓
                                              K-Type Thermocouple ← Oven Chamber
```

---

## Programming Each Unit (5 minutes)

### Step 1 — Initial Settings

Hold **SET + DOWN arrow together for 3 seconds** to enter Initial Settings menu.

| Parameter | Set to | Purpose |
|---|---|---|
| SL1 | `K` | K-type thermocouple input |
| SL2 | `0001` | Fahrenheit, heating only |
| SL4 | `0011` | Process high alarm (overheat safety) |
| SL5 | `0000` | Alarm 2 disabled |
| SLH | `870` | Max temperature customer can set |
| SLL | `100` | Min temperature customer can set |
| oH | `2` | 2°F hysteresis for ON/OFF |
| AH1 | `2` | Alarm hysteresis |

Press SET to confirm each, then hold SET to exit back to normal display.

### Step 2 — PID and Alarm Settings

Hold **SET alone for 3 seconds** to enter Parameter menu.

| Parameter | Set to | Purpose |
|---|---|---|
| AL1 | `900` | Overheat alarm — kills output at 900°F |
| ATU | `1` | Start auto-tune (run at typical operating temp ~500°F) |

Wait 10-20 minutes for auto-tune to complete (display flashes "AT" then stops).
Auto-tune sets P, I, D values automatically. Do NOT change them after.

| Parameter | Set to | Purpose |
|---|---|---|
| Ar | `50` | Anti-reset windup |
| T | `2` | Output cycle time (2 sec for SSR) |

### Step 3 — Engineering Menu

Hold SET, scroll to **COD**, enter `0001`.

| Parameter | Set to | Purpose |
|---|---|---|
| dF | `0` | Disable digital filter (causes false readings if enabled) |

### Step 4 — Lock It Down

Hold SET for 3 seconds, scroll to **LCK**, set to `0110`.

**Customer can now ONLY change target temperature between 100–870°F.**
All menus, PID settings, alarms, and limits are invisible and locked.

### Step 5 — Set DH48S Timer

Set DH48S-2Z timer to 6 hours. When customer turns unit on, timer counts down
and cuts power at 6 hours automatically.

---

## What The Customer Experiences

- Plug in, flip On/Off switch
- Display shows current temperature (top, red) and target temperature (bottom, green)
- Press SET briefly to change target temp (100–870°F only)
- Use arrow buttons to adjust
- Oven heats to target and holds it
- Auto-shutoff at 6 hours
- Turn off when done

That's it. No menus. No confusion. No manual needed.

---

## Security — What Customers CANNOT Do

| Action | Result |
|---|---|
| Set temp above 870°F | Blocked by SLH |
| Set temp below 100°F | Blocked by SLL |
| Access PID settings | Blocked by LCK |
| Access initial settings menu | Blocked by LCK |
| Factory reset | No such feature exists |
| Accidentally change settings | Impossible |

Settings survive power outages (stored in EEPROM / non-volatile memory).
No reset button. No backdoor. Locked is locked.

---

## Three-Layer Safety System

1. **REX-C100** — Max setpoint locked at 870°F (software limit)
2. **AL1 alarm at 900°F** — Controller kills output if temp exceeds 900°F
3. **Thermal fuse on oven body (~930°F)** — Permanently cuts power if controller fails

---

## Reliability

- REX-C100: solid state, no moving parts, 10+ year lifespan
- Settings: EEPROM, survives unlimited power cycles
- SSR: most likely part to wear out first (replace every few years if needed)

### Protect Against

| Risk | Solution |
|---|---|
| Power surge | Inline fuse ($0.50) |
| Thermocouple breaks | AL1 alarm triggers on open circuit |
| SSR fails stuck-on | Thermal fuse melts and cuts power |
| Liquid ingress | Seal controller box enclosure |

---

## REX-C100 Menu Reference

**Two different menus accessed by different button combos:**

| How to enter | Menu | Contains |
|---|---|---|
| Hold SET (3 sec) | Parameter menu | P, I, D, AT, AL1, AL2, Ar, T, LCK |
| Hold SET + DOWN (3 sec) | Initial Settings | SL1, SL2, SL4, SL5, SLH, SLL, oH, AH1, AH2, Pb |

**LCK (Lock) codes:**

| Code | Effect |
|---|---|
| 0100 | Everything unlocked (for your setup) |
| 0110 | Only target temp changeable (for customers) |
| 0101 | Everything locked |
| 0111 | Total lockout |

**SL2 (Temperature unit) codes:**

| Code | Effect |
|---|---|
| 0000 | Celsius, heating only |
| 0001 | Fahrenheit, heating only |
| 0010 | Celsius, heating + cooling |
| 0011 | Fahrenheit, heating + cooling |

---

## Future Scaling

At 100+ units, consider sourcing a custom OEM controller from Alibaba:
- Single knob for temp, built-in timer, no menus
- Search: "oven temperature controller with timer OEM"
- Send spec: K-type input, SSR output, 100–870°F, 6hr timer, custom logo
- Expected cost: $12-22/unit at 100 pcs, $6-12/unit at 1000 pcs
- Ask for UL/ETL certification if selling retail in US

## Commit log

2026-09-28 Heat-N-Clean Glass Oven: current approved base + lid (2026-09-28)
    History wiped on Matt's request; older versions kept offline only.
    [ceramic heater_CAD.step]
2026-09-28 Lid assembly: insulation packed, then ceramic lid disk glued in with high-heat adhesive (Matt's method)
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2026-09-28 Complete oven viewer: base + lid open on the hinge, cut across the hinge line, separate
2026-09-28 Wire + thermocouple route moved inside: 3 holes in the support ring plate and bottom cap at r58 (183°, 188° Ø8; 315° Ø6.4); inner-wall wire slot and TC hole closed; old tube-gap holes in the bottom c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
2026-09-28 Inner wall: close the mirror-image holes (~3°, ~134.6°) the radial cutter punched opposite the wire slot and TC hole; glass slots and all 18 bolt holes verified open
2026-09-28 Machining package 2026-09-28 (STEP+STL, bilingual README) built reproducibly from the approved design; parts sheet re-rendered with the wire-hole changes
    [01_Inner_Wall_Tube.step, 01_Inner_Wall_Tube.stl, 02_Outer_Perforated_Tube.stl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]
2026-09-28 Top cap redrawn as a clean solid (STEP): flat top on the tubes, open over the ceramic, 0.2 mm sleeves, 6 bolt tabs, 4 glass slots, vents; lid raised 1.2 mm to sit on it (ceramic lid disk still on the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
    [01_Inner_Wall_Tube.step, 03_Support_Ring.step, 04_Bottom_Cap.step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]
2026-09-28 Hinge left to Tianrun's shop (stock butt hinge); noted in the package README
2026-09-29 Top cap: metal U-groove under each glass slot (covers the insulation, keeps the cap one piece); slots no longer cut the cap into 4 pieces
    [01_Inner_Wall_Tube.step, 03_Support_Ring.step, 04_Bottom_Cap.step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]
2026-09-29 Top cap grooves now match the ceramic slot exactly: 10.5 wide, round R5.25 bottom, flush with the ceramic
    [01_Inner_Wall_Tube.step, 03_Support_Ring.step, 04_Bottom_Cap.step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]
2026-09-29 Top cap: one continuous groove per slot (ceramic to outer tube); inner tube glass slots widened to 13.3 so the groove passes
    [01_Inner_Wall_Tube.step, 01_Inner_Wall_Tube.stl, 03_Support_Ring.step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]
2026-09-29 Parts sheet re-rendered with the grooved top cap; inner tube STEP fused into one solid; CURRENT.md notes
    [01_Inner_Wall_Tube.step, 01_Inner_Wall_Tube.stl, 03_Support_Ring.step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]
2026-09-30 Fit audit 2026-09-30: leg holes Ø6.6 at r64, heater holes 180/190, 03 and 09 clearances, lid tubes on 09 plate, 01 slot step and 04 skirt pockets closed
    [01_Inner_Wall_Tube.step, 01_Inner_Wall_Tube.stl, 03_Support_Ring.step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]
2026-09-30 Lid handle screws on: 2 x Ø4.5 holes in 08, M4 tapped posts in 10, handle seated on the disk
    [01_Inner_Wall_Tube.step, 03_Support_Ring.step, 04_Bottom_Cap.step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]
2026-09-30 Parts sheet re-rendered 2026-09-30 (fit fixes, lid top disk shown from underneath with handle holes)
2026-10-16 Machining package 2026-10-16: ceramic seat raised 5.06 so the real ceramic is flush with the top cap
    Tianrun's plastic print on the real ceramic: ceramic top 5.06 mm below the 05 cap top, ceramic slots ~5.3 deeper
    than the grooves. Ceramic does not change; same 13 parts, no spacer.
    - 03: middle (r 36.25-52) raised 5.06, centering wall up with it; bolts, leg and wire holes unchanged
    - 05: groove bottoms 0.24 deeper (z 67.26) to meet the ceramic slot bottoms
    - 01: glass slots 0.24 lower with the grooves (0.2 clearance kept)
    - 09: lid disk pocket + shelf +1.2 (lid disk face flush with the lid bottom)
    FAB_PACKAGE_2026-09-28 moved to the local archive. verify_steps.py gains a package mode (one so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
2026-10-16 Raised-seat preview (2026-10-12): assembly viewer, video and diagrams sent to Tianrun; seat5 meshes as real blobs for Pages
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2026-11-08 Shrink the oven 8 mm in diameter so the glass slurper fits the top cap ring (2026-11-08)
    Insulation between the ceramic and the inner tube 24.6 -> 20.6 mm. Every body and lid
    radius at or outside the inner tube moves in 4.0 mm: 01/06 ID 133.7, 02/07 OD 146.5,
    04/08 OD 149.5, 05 ring width 32.4 -> 28.4 and grooves 25.1 long, 03/09 walls, leg holes
    r 60, hinge pivot r 77.5, ceramic spacer rings ID 136.1 / OD 144.1. Heights, thicknesses,
    hole sizes, slot widths, the air gap and the ceramics are unchanged.
    New FAB_PACKAGE_2026-11-08 (STEP + STL + bilingual README), all single solids. 01, 02,
    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
2026-11-08 Viewer bolts: keep each bolt set as its own mesh, moved in 4.0 with the tubes (idempotent)
2026-11-08 09 Lid Ceramic Holder: 48 vent holes Ø3.5 at r 69.85, aligned with the 05 top cap vents; outer lip notched at each hole
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2026-11-08 Remove old-design files (old renders, build video, QC shots, viewer-thickness, 23 old generator scripts); PARTS_LIST regenerated from the 2026-11-08 package; README and assembly texts brought up to d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
2026-11-08 Print set 2026-11-08: 18 STL for a plastic fit/display print (12 metal parts, 6 ceramic solids with STEP), README EN + 中文; tray 14 and fasteners not included
2026-11-08 R2: body 2.66 mm taller above the seat so the real ceramic (core 90.4 + base plate 4.9 = 95.3) sits flush with the top cap
    01 and 02 are 125.36 tall (top bolt ring 59 -> 61.66, glass slots +2.66, 02 perforation rows re-spaced, same Ø4 @ 6);
    05 and the whole lid are the same parts 2.66 higher; 03, 04, 14, the seat and everything below it do not move.
    hnc_params.body_raise drives it (HNC_RAISE=0 rebuilds the first 2026-11-08 package exactly). New FAB_PACKAGE_2026-11-08-R2,
    PRINT_SET_2026-11-08-R2 (C1 90.4, C2 4.9), change sheets, viewer meshes, self-building MP4, parts sheet, product renders,
    PARTS_LIST (Scripts/make_parts_list.py). The 2026-11-08 package, print set and their renders are remo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
2026-11-10 Spacer rings: one size, all five 10 mm centred on their bolts; phone print list
2026-11-12 Top cap ring 28.4 -> 20.0 mm for the smallest glass slurper (2026-11-12)
    Insulation 20.6 -> 14.6, air gap 4.4 -> 3.0, top cap edge 0.5 past the outer tube.
    New FAB_PACKAGE_2026-11-12 and PRINT_SET_2026-11-12; R2 package and print set moved to the archive.
    05 loses its outer skirt (tabs stay outside the tube), vents 3.0, 03 riser on the centering wall,
    wire holes r 53.5 with the lead holes at 185/195, legs r 54; 04/08 skirts stay 1.5 past the tube.
    Viewer meshes, parts list and print list regenerated; see CURRENT.md.
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2026-11-12 Every picture, video and sheet redone for the 2026-11-12 design (ring 20.0, 5 bolts per ring, hinge 257.5, legs 5.5/125.5/245.5)
    Product + hero stills at the 11-08 quality, build MP4, parts sheet, 11-08-R2 -> 11-12 change sheets,
    print-list pictures, simple top-down drawing; README points at viewer-oven.html and the new files.
    Replaced files moved to the local archive folder.
2026-11-12 Wording fixes: 5 cap tabs 72 deg apart, cap edge 0.4 past the outer tube, M6 / M5 / M4 hardware, hinge is the factory's stock butt hinge
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2026-11-12 Viewer: label button only shows on the whole oven when separated (replaces auto-separate)
